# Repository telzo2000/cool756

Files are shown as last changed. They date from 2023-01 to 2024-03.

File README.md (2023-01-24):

# cool756

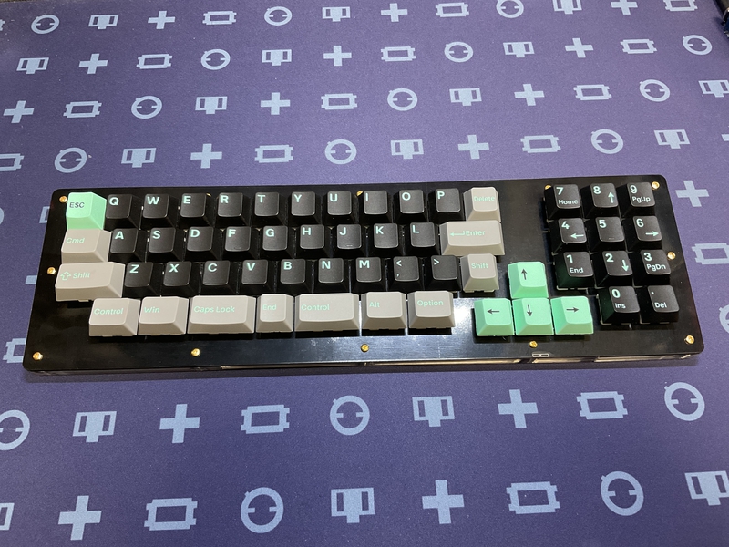
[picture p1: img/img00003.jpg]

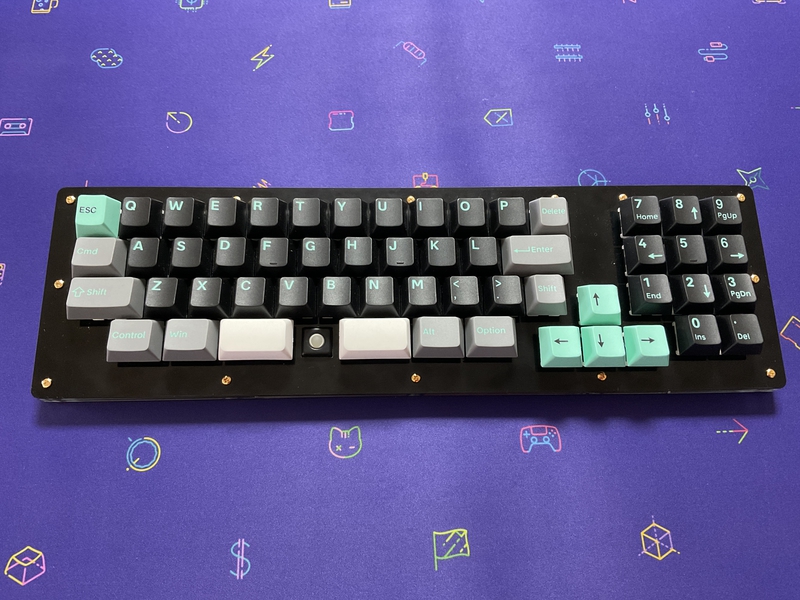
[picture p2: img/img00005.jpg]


<br>

# What is cool756?

cool756 is designed by m.ki.
<br>
cool756 is a keyboard.
<br>
This keyboard has 56 keys or 55keys and trackball.
<br>
<br>

# build guide

https://github.com/telzo2000/cool756/blob/main/buildguide_for_cool756.md
<br>

# firmware

https://github.com/telzo2000/cool756/tree/main/firmware
<br>
# Sales site

https://mki0002ozlet.booth.pm/items/4491960

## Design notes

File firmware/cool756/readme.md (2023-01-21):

# cool753rp

cool753rp

*A short description of the keyboard/project*

* Keyboard Maintainer: [m.ki](https://github.com/telzo2000)
* Hardware Supported: *The PCBs, controllers supported*
* Hardware Availability: *Links to where you can find this hardware*

Make example for this keyboard (after setting up your build environment):

    make cool753rp:default

Flashing example for this keyboard:

    make cool753rp:default:flash

See the [build environment setup](https://docs.qmk.fm/#/getting_started_build_tools) and the [make instructions](https://docs.qmk.fm/#/getting_started_make_guide) for more information. Brand new to QMK? Start with our [Complete Newbs Guide](https://docs.qmk.fm/#/newbs).

## Bootloader

Enter the bootloader in 3 ways:

* **Bootmagic reset**: Hold down the key at (0,0) in the matrix (usually the top left key or Escape) and plug in the keyboard
* **Physical reset button**: Briefly press the button on the back of the PCB - some may have pads you must short instead
* **Keycode in layout**: Press the key mapped to `QK_BOOT` if it is available

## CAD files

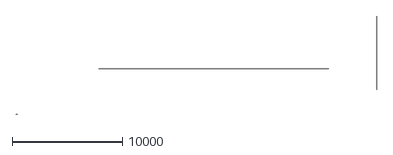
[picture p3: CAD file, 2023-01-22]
case_design/separate_moddleplate/cool756casedesign.dxf
32714.4 x 8895.2

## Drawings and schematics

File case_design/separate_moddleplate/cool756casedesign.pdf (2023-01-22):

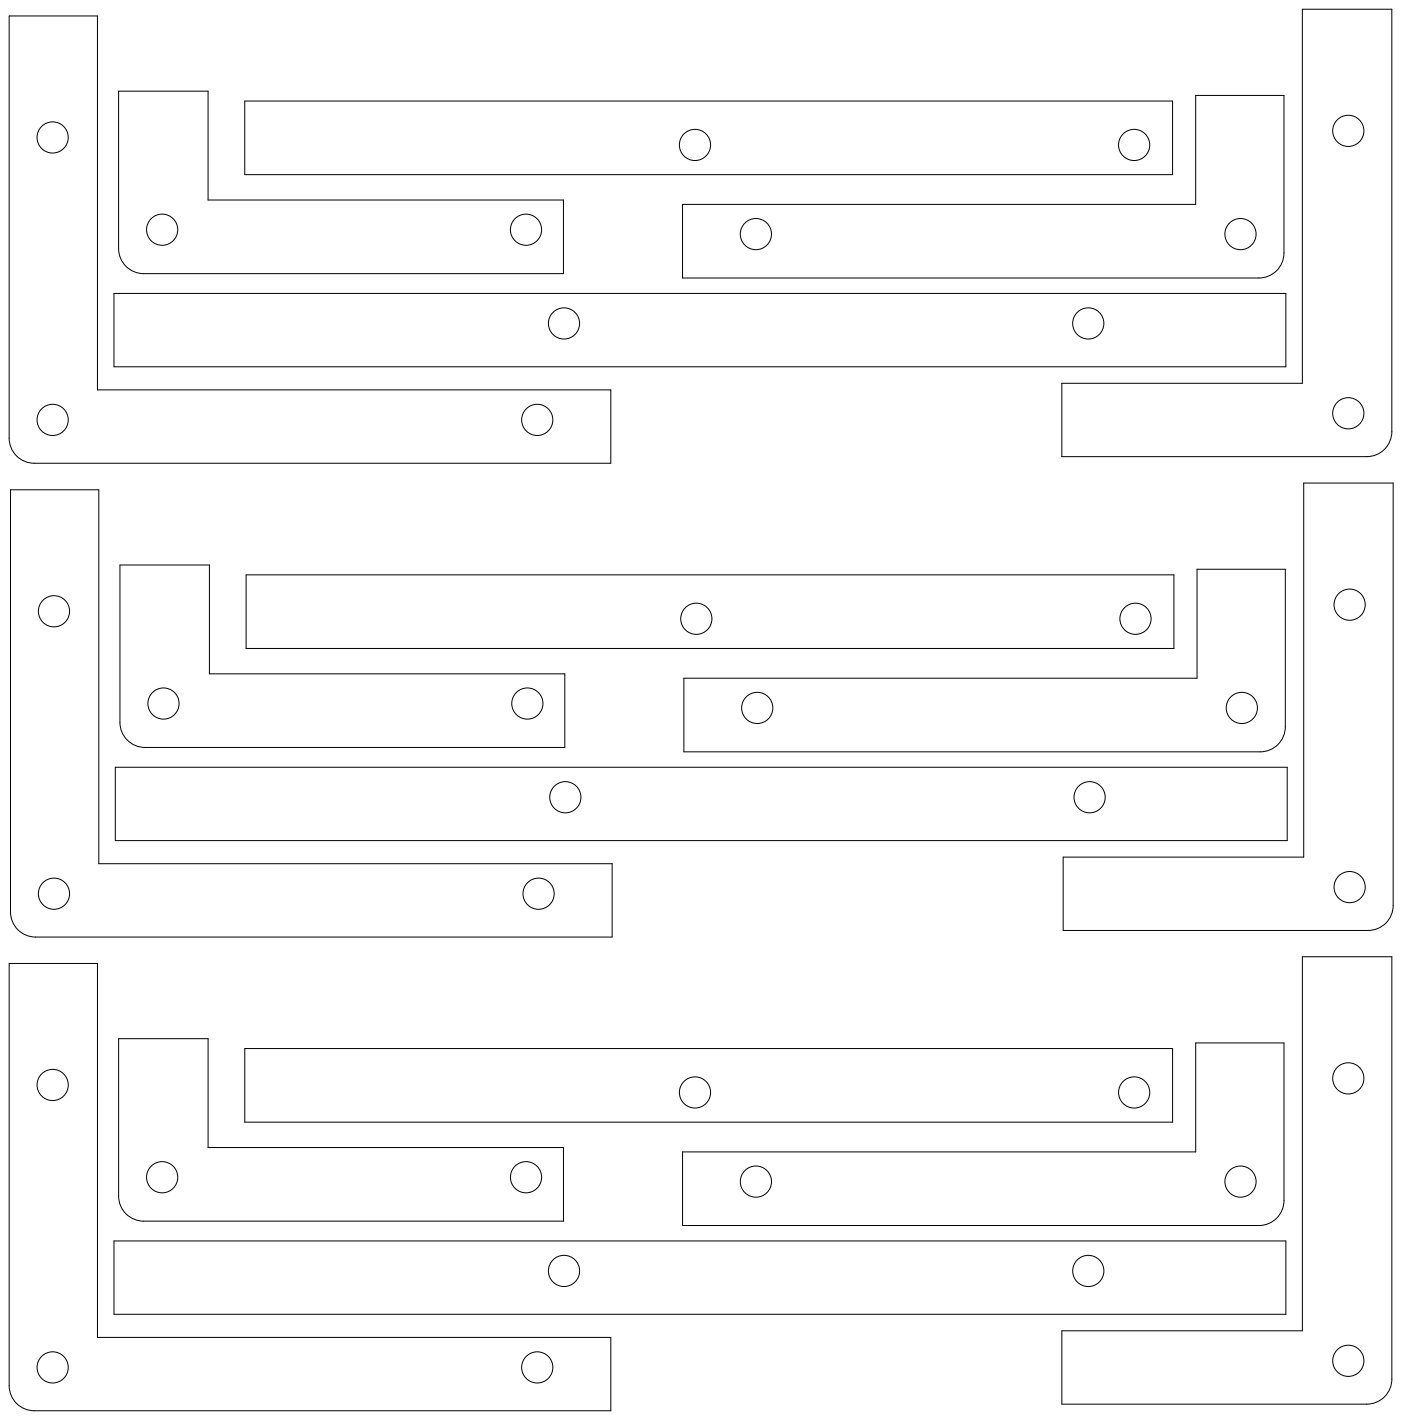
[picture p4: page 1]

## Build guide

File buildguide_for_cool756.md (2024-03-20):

# Build guide(cool756 ver.1.0)

## Parts list

| No. | Patrs | Quantity | remarks | Suppliers | Cost |
|--|--|--|--|--|--|
|番号|名前|数|備考|調達先|参考価格（送料込）|<br>
|1|PCB|1|50%keyboard<br>keyboard|[elecrow](https://www.elecrow.com)<br>[JLCPCB](https://jlcpcb.com)<br>[ALLPCB](https://www.allpcb.com)|10枚で130〜140ドル|<br>
|2-1|Switch Plate<br>スイッチプレート|１|↑|↑|↑|
|2-2|Bottom Plate<br>ボトムプレート|１|↑|↑|↑|
|3|M2screw<br>M2ネジ|26|4mm<br>CoverPlateで使用|DIYショップなど|10本で100円程度|
|4|M2spacer<br>M2スペーサー|13|8mmメス-メス|[ヒロスギネット](https://www.hirosugi-net.co.jp/shop/c/c10/)<br>[遊舎工房](https://yushakobo.jp)|20本で800円程度|
|5|pro micro|1|ピンヘッダ含む|[遊舎工房](https://yushakobo.jp)<br>[Talp Keyboard](https://talpkeyboard.net)<br>[Daily Craft Keyboard](https://shop.dailycraft.jp)等|価格変動中|
|6|Swith socket<br>スイッチソケット|56|cherry MX互換<br>無くても可|[遊舎工房](https://yushakobo.jp)<br>[Talp Keyboard](https://talpkeyboard.net)<br>[Daily Craft Keyboard](https://shop.dailycraft.jp)等|10個で165円程度|
|7|Diode<br>ダイオード|56|リードタイプでもSMDでも可|[遊舎工房](https://yushakobo.jp)<br>[Talp Keyboard](https://talpkeyboard.net)<br>[Daily Craft Keyboard](https://shop.dailycraft.jp)等|100個で220円程度から|
|８|Trackball|1|PIM447|[PIMONORI](https://shop.pimoroni.com)<br>[マルツ](https://www.marutsu.co.jp/pc/i/32844496/)|3000円程度

この他に、USBケーブル、キーキャップ等が必要です。
<br><br>

## Firmware

参考<br>

https://github.com/telzo2000/Hello_keyboard/blob/main/readme_about_firmware.md

[Here](https://github.com/telzo2000/cool756/tree/main/firmware)

<br>
[remap](https://remap-keys.app/)

<br>
<br><br>

## Build

Please read it and then work on it.
<br>
一読してから、作業をしてください。
<br><br>

### 1 Parts check

Front side（表面）<br>
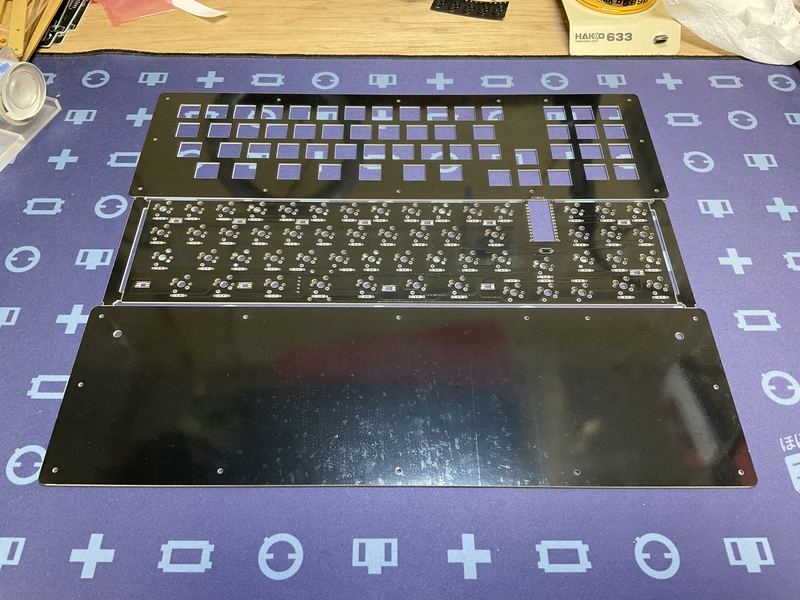
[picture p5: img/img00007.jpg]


Please cut.
<br>
切り離してください。
<br>
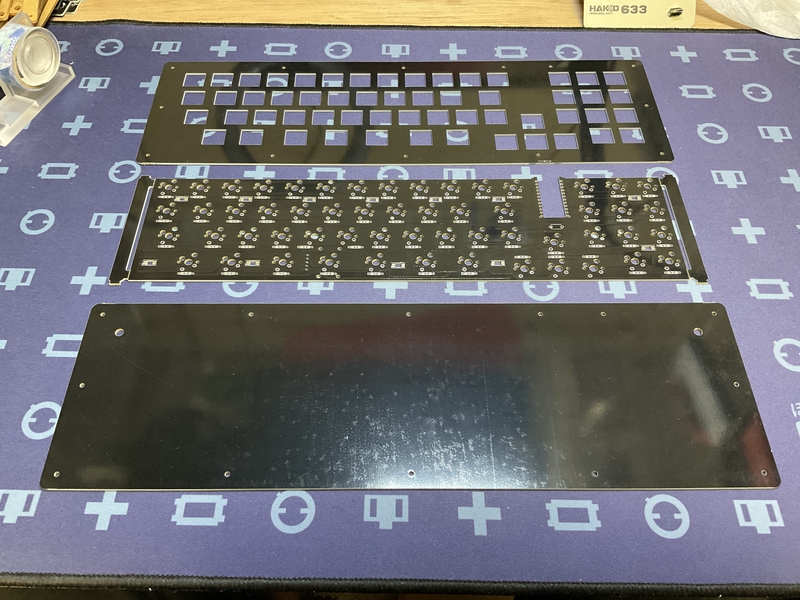
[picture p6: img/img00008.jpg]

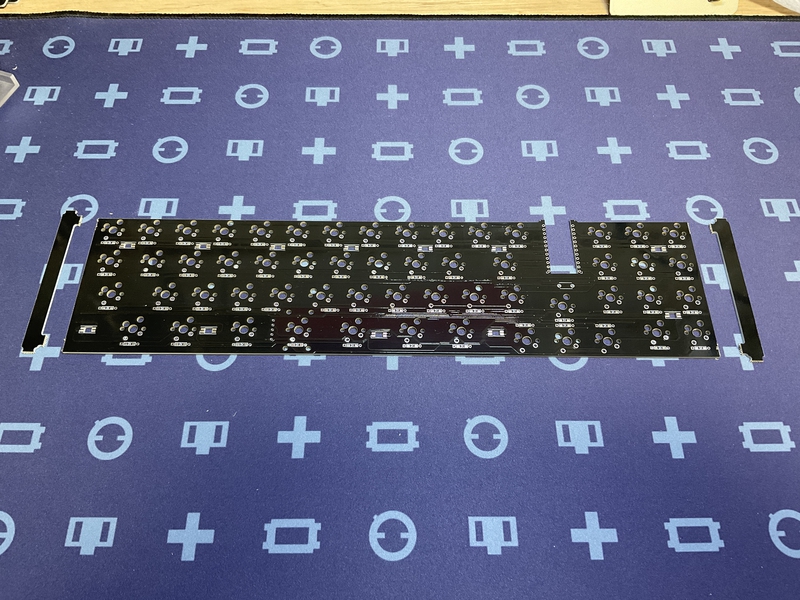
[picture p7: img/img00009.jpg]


<br><br>

### 2 Diode soldering

Solder the diode on the back side.
<br>
裏面にダイオードのハンダ付けをします。
<br>

There are lead type and SMD diodes.
<br>
ダイオードはリードタイプか、SMDがあります。
<br>
Here, we will explain the lead type soldering.
<br>
ここでは、リードタイプのハンダ付けの説明をします。
<br>
However, those who adopt the choc switch should use SMD diodes.
<br>
ただし、chocスイッチを採用する人は、SMDのダイオードを使用してください。
<br>

Use a lead bender to bend the legs of the diode.
<br>
リードベンダーを使い、ダイオードの足を曲げます。
<br>

Insert the diode into the board.
<br>
ダイオードを基板に挿しこみます。
<br>

Please pay attention to the orientation of the diode.
<br>
ダイオードの向きに注意してください。
<br>

Secure the diode with masking tape, then face up.
<br>
マスキングテープでダイオードを固定してから、表面を上にします。
<br>
Solder the protruding legs.
<br>
はみ出ている足部分に、ハンダ付けをします。
<br>
After soldering, use nippers to cut off the protruding legs.
<br>
はんだ付けが終わったら、はみ出ている足をニッパーで切り取ってください。
<br>

[８倍速　Diodeハンダ付け動画](https://youtu.be/Yaodh2-XxV4)

<br>
<br>

## Case 1
If you use cool756 with hot swap, please proceed here.
<br>
cool756をホットスワップで使用する場合、こちらを進めてください。

### 3 Soldering switch sockets

Solder the switch sockets on the back side.
<br>
裏面にスイッチソケットのハンダ付けをします。
<br>
ここでは、cherryMXスイッチのハンダ付けを行います。
<br>
Place the switch socket so that the white silk is hidden.
<br>
白いシルクが隠れるように、スイッチソケットを乗せてください。
<br>
That is the correct switch socket orientation.
<br>
それが正しいスイッチソケットの向きになります。
<br>
When using a choc switch, place the switch socket so that the letters choc are hidden.
<br>

Apply solder to both pads.
<br>
両方のパッドにハンダを盛ります。
<br>
Place the switch socket and fix it with a warm soldering iron while melting the solder.
<br>
スイッチソケットを乗せて、温めたハンダゴテで、ハンダを溶かしながら、固定します。
<br>
You can make it easier by working while holding it with tweezers.
<br>
ピンセットで押さえながら、作業をすると楽にできます。
<br>

[８倍速　Switch socketハンダ付け動画](https://youtu.be/E__mHvmIXQo)

<br><br>

### 4 Pro micro

Solder the pro micro.
<br>
pro microのハンダ付けをします。
<br>
For cool756, in order to pursue thinness, the pro micro is attached directly to the board without using a pin header.
<br>
cool756では、薄さを求めるために、pro microをピンヘッダを使わずに、基板に直付けします。
<br>
Here, it is the surface with the USB terminal and parts of the pro micro.
<br>
ここでは、pro microのUSB端子や部品が付いている表面とします。
<br>
<br>
Install the pro micro surface facing the PCB side.
A part of the PCB is cut out so that the pro micro's USB terminal and parts do not interfere with the PCB.
<br>
pro microの表面がPCB側に向くよう取り付けます。
pro microのUSB端子や部品がPCBに干渉しないよう、PCBの一部が切り抜かれています。
<br>
Place the pro micro so that the "RAW" printed on the pro micro is on the numeric keypad side.
<br>
pro microの設置向きは、pro microの「RAW」の印字がテンキー側にしてください。
<br>
<br>
＜If you have a breadboardブレッドボードがある場合＞
<br>
The installation procedure is as follows.
<br>
取り付け方は次の手順になります。
<br>
①Insert the pin header into the breadboard, and pass the pin header through the pro micro with the surface facing the breadboard.
<br>
①ブレッドボードにピンヘッダを挿して、pro microの表面をブレッドボード側に向けて、ピンヘッダを通します。
<br>
② Solder from the back side of pro micro and fix the pin header.
<br>
②pro microの裏面からハンダ付けをして、ピンヘッダを固定します。
<br>
③Pull out the pro micro from the breadboard.
<br>
③ブレッドボードからpro microを抜きます。
<br>
④Remove the plastic attached to the pin header using radio pliers or the like.
<br>
④ピンヘッダに付いているプラスチックをラジオペンチ等を用いて、外します。
<br>
⑤ Insert so that the surface of pro micro faces the PCB side. Temporarily fix with masking tape.
<br>
⑤pro microの表面がPCB側に向くように、挿します。マスキングテープ等で仮固定します。
<br>
⑥ Solder from the opposite side of the PCB where the pro micro is inserted. Cut pins that are too long with nippers.
<br>
⑥pro microを挿したPCBの反対側からハンダ付けをします。長すぎるピンはニッパー等で切ってください。
<br>
<br>
＜If you don't have a breadboardブレッドボードがない場合＞
<br>

The installation procedure is as follows.
<br>
取り付け方は次の手順になります。
<br>
①Insert the pin header from the back of pro micro, then pro micro, then PCB.
Temporarily secure with masking tape.
<br>
①ピンヘッダをpro microの裏面から、pro micro、PCBの順で挿します。
マスキングテープで仮固定します。
<br>
②Solder the pin header from the PCB side.
<br>
②PCB側からピンヘッダをハンダ付けします。
<br>
③Remove the plastic pin header on the back of the pro micro using needle nose pliers.
<br>
③pro micro裏面のピンヘッダのプラスチックをラジオペンチ等を用いて、外します。
<br>
④Solder the back of the pro micro. Cut pins that are too long with nippers.
<br>
④pro microの裏面のハンダ付けをします。長すぎるピンはニッパー等で切ってください。
<br>
<br>

### 5　Test

Please write the firmware and check the operation.
<br>
ファームウェアを書き込んで、動作確認をしてください。
<br>

Install a switch or measure continuity with tweezers, etc.
<br>
スイッチを取り付けるか、ピンセット等で導通をはかるかを行います。
<br>
<br>

Firmware

[github](https://github.com/telzo2000/cool756/tree/main/firmware)

[remap](https://remap-keys.app/)

<br>
If you have a switch that doesn't respond, use a hot soldering iron to warm up the switch socket,diode and pro micro terminals.
<br>
もし、反応しないスイッチがあったら、温めたハンダゴテで、そのスイッチソケットやダイオード、pro microの端子を温めてください。
<br>
Also make sure the diode is oriented correctly.
<br>
また、ダイオードの向きが正しいか確認してください。
<br>

### 6 Installation of key switch

Plug the key switch into the switch plate and then into the switch socket on the PCB.
<br>
スイッチプレートにキースイッチを差し込み、そのあと、PCBのスイッチソケットに差し込んでください。
<br>
<br>

### 7 Bottom plate

Insert the M2 screw from the bottom surface of the bottom plate and tighten it with the M2 spacer on the top surface.
<br>
ボトムプレートの下面からM2ネジを差し込み、上面でM2スペーサーで締めてください。
<br>
13 locations.
<br>
13箇所行います。
<br>
<br>

### Option Middle plate

If you have the optional middle plate, please install the aluminum feet first.
<br>
オプションのミドルプレートがある場合、最初に、アルミ足を取り付けてください。
<br>
<br>
Next, stack the acrylic parts so that they pass through the bottom plate spacer.
<br>
次にボトムプレートのスペーサーを通すように、アクリル部品を重ねてください。
<br>
<br>
### 8 Finish

Place the switch plate and PCB on the bottom plate and tighten the 13 M2 screws.
<br>
ボトムプレートの上に、スイッチプレートとPCBを載せて、M2ネジで13箇所を締めてください。
<br>
<br>
ミドルプレート使用時<br>


<br>
<br>

## Case2

If you want to solder directly without using a switch socket, proceed here.
<br>
スイッチソケットを使用せず、直接ハンダ付けをする場合は、こちらを進めてください。
<br>
<br>

### 3 Switch plate

Insert your favorite key switch from the top of the switch plate.
<br>
スイッチプレートの上面から、お好みのキースイッチを差し込んでください。
<br>

Note the orientation of the key switch.
<br>
キースイッチの向きに注意してください。
<br>
Good<br>
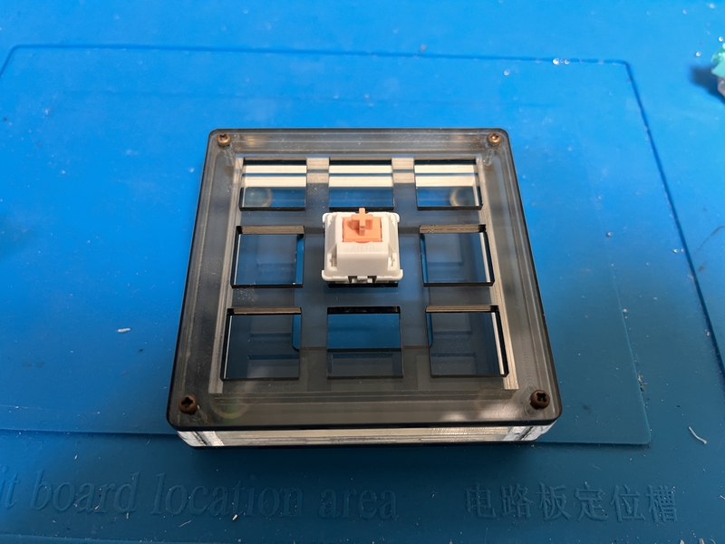
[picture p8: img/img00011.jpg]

<br>
Not good<br>
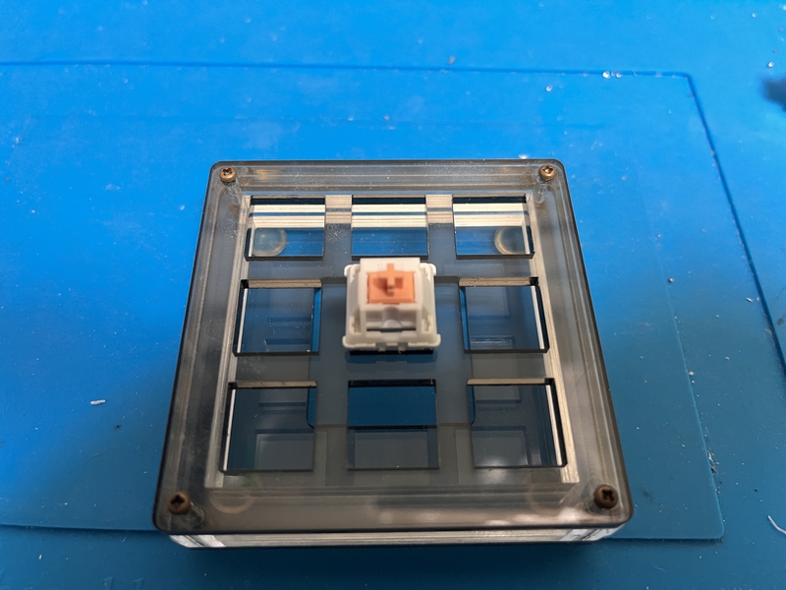
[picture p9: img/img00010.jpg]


<br>
<br>

### 4 Pro micro

Solder the pro micro.
<br>
pro microのハンダ付けをします。
<br>
For cool756, in order to pursue thinness, the pro micro is attached directly to the board without using a pin header.
<br>
cool756では、薄さを求めるために、pro microをピンヘッダを使わずに、基板に直付けします。
<br>
Here, it is the surface with the USB terminal and parts of the pro micro.
<br>
ここでは、pro microのUSB端子や部品が付いている表面とします。
<br>
<br>
Install the pro micro surface facing the PCB side.
A part of the PCB is cut out so that the pro micro's USB terminal and parts do not interfere with the PCB.
<br>
pro microの表面がPCB側に向くよう取り付けます。
pro microのUSB端子や部品がPCBに干渉しないよう、PCBの一部が切り抜かれています。
<br>
Place the pro micro so that the "RAW" printed on the pro micro is on the numeric keypad side.
<br>
pro microの設置向きは、pro microの「RAW」の印字がテンキー側にしてください。
<br>
<br>
＜If you have a breadboardブレッドボードがある場合＞
<br>
The installation procedure is as follows.
<br>
取り付け方は次の手順になります。
<br>
①Insert the pin header into the breadboard, and pass the pin header through the pro micro with the surface facing the breadboard.
<br>
①ブレッドボードにピンヘッダを挿して、pro microの表面をブレッドボード側に向けて、ピンヘッダを通します。
<br>
② Solder from the back side of pro micro and fix the pin header.
<br>
②pro microの裏面からハンダ付けをして、ピンヘッダを固定します。
<br>
③Pull out the pro micro from the breadboard.
<br>
③ブレッドボードからpro microを抜きます。
<br>
④Remove the plastic attached to the pin header using radio pliers or the like.
<br>
④ピンヘッダに付いているプラスチックをラジオペンチ等を用いて、外します。
<br>
⑤ Insert so that the surface of pro micro faces the PCB side. Temporarily fix with masking tape.
<br>
⑤pro microの表面がPCB側に向くように、挿します。マスキングテープ等で仮固定します。
<br>
⑥ Solder from the opposite side of the PCB where the pro micro is inserted. Cut pins that are too long with nippers.
<br>
⑥pro microを挿したPCBの反対側からハンダ付けをします。長すぎるピンはニッパー等で切ってください。
<br>
<br>
＜If you don't have a breadboardブレッドボードがない場合＞
<br>

The installation procedure is as follows.
<br>
取り付け方は次の手順になります。
<br>
①Insert the pin header from the back of pro micro, then pro micro, then PCB.
Temporarily secure with masking tape.
<br>
①ピンヘッダをpro microの裏面から、pro micro、PCBの順で挿します。
マスキングテープで仮固定します。
<br>
②Solder the pin header from the PCB side.
<br>
②PCB側からピンヘッダをハンダ付けします。
<br>
③Remove the plastic pin header on the back of the pro micro using needle nose pliers.
<br>
③pro micro裏面のピンヘッダのプラスチックをラジオペンチ等を用いて、外します。
<br>
④Solder the back of the pro micro. Cut pins that are too long with nippers.
<br>
④pro microの裏面のハンダ付けをします。長すぎるピンはニッパー等で切ってください。
<br>
<br>

### 5　Test

Please write the firmware and check the operation.
<br>
ファームウェアを書き込んで、動作確認をしてください。
<br>
Check for continuity with tweezers or the like.
<br>
ピンセット等で導通をはかるかを行います。
<br>
<br>

Firmware

[github](https://github.com/telzo2000/cool756/tree/main/firmware)

[remap](https://remap-keys.app/)

<br>
If you have a switch that doesn't respond, use a hot soldering iron to warm up the diode and pro micro terminals.
<br>
もし、反応しないスイッチがあったら、温めたハンダゴテで、ダイオードやpro microの端子を温めてください。
<br>
Also make sure the diode is oriented correctly.
<br>
また、ダイオードの向きが正しいか確認してください。
<br>
<br>

### 6 Soldering keyswitch

Turn the switch plate with the key switch upside down.
<br>
キースイッチの刺さったスイッチプレートを逆さの向きにします。
<br>
Stack the PCBs in the same way upside down.
<br>
同じ様に逆さの向きにしたPCBを重ねます。
<br>
<br>
Check to see if the key switch legs are sticking out of the PCB.
<br>
PCBからキースイッチの足が出ているか確認してください。
<br>
If it's OK, solder all the key switch legs and PCB terminals.
<br>
問題ないのであれば、全てのキースイッチの足とPCBの端子をはんだ付けします。
<br>
<br>
### 7 Bottom plate

Insert the M2 screw from the bottom surface of the bottom plate and tighten it with the M2 spacer on the top surface.
<br>
ボトムプレートの下面からM2ネジを差し込み、上面でM2スペーサーで締めてください。
<br>
13 locations.
<br>
13箇所行います。
<br>
<br>

### Option Middle plate

If you have the optional middle plate, please install the aluminum feet first.
<br>
オプションのミドルプレートがある場合、最初に、アルミ足を取り付けてください。
<br>
<br>
Next, stack the acrylic parts so that they pass through the bottom plate spacer.
<br>
次にボトムプレートのスペーサーを通すように、アクリル部品を重ねてください。
<br>
<br>

### 8 Finish

Place the switch plate and PCB on the bottom plate and tighten the 13 M2 screws.
<br>
ボトムプレートの上に、スイッチプレートとPCBを載せて、M2ネジで13箇所を締めてください。
<br>
<br>
ミドルプレート使用時<br>



<br>
<br>

### Option  Installing PIM447 Trackball

A PIM447trackball can be attached to the cool756.
<br><br>
cool756に、PIM447trackballを取り付けることができます。
<br>
<br>
In addition to PIM447, four M2 screws 8mm (low head screws), eight M2 nuts, and a pin header are required.
<br><br>
PIM447との他に、M2ネジ8mm４本（低頭ネジ）、M2ナット８個、ピンヘッダが必要となります。
<br><br>
上からネジを差し込み、下でナットを締めます。<br>
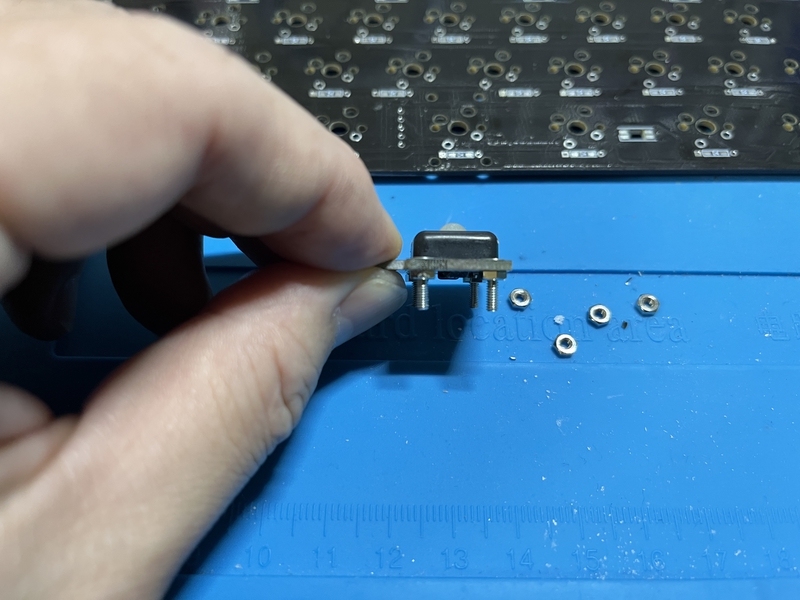
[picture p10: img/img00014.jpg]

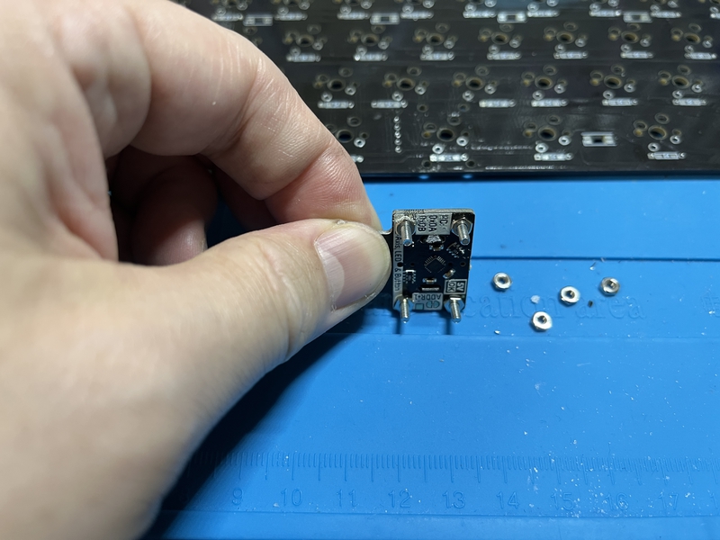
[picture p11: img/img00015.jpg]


PCBに差し込んで、その下からナットを締めます。<br>
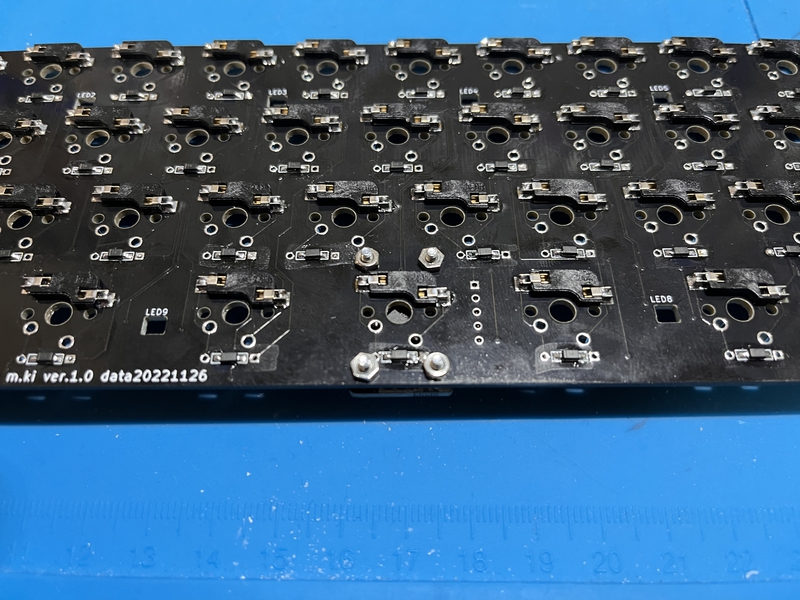
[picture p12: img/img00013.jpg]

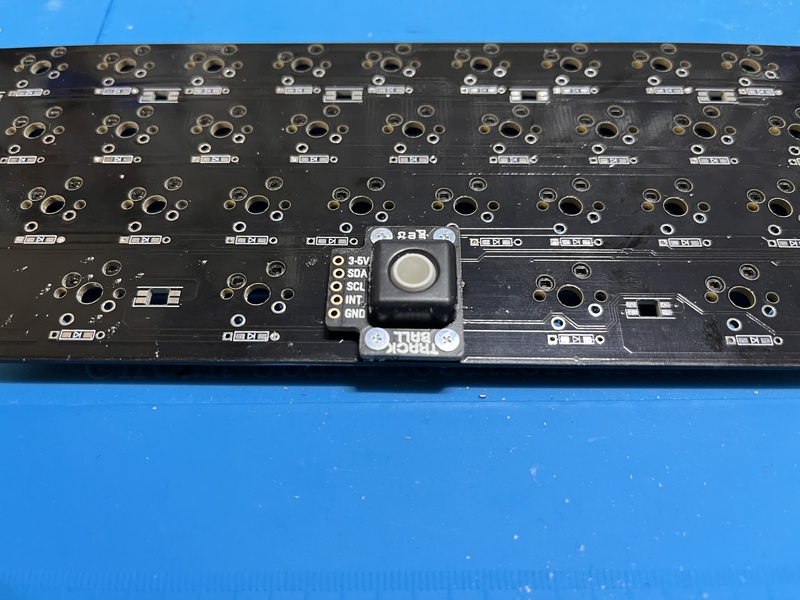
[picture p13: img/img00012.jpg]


ピンの長さを調節して、差し込んではんだ付けをします。<br>
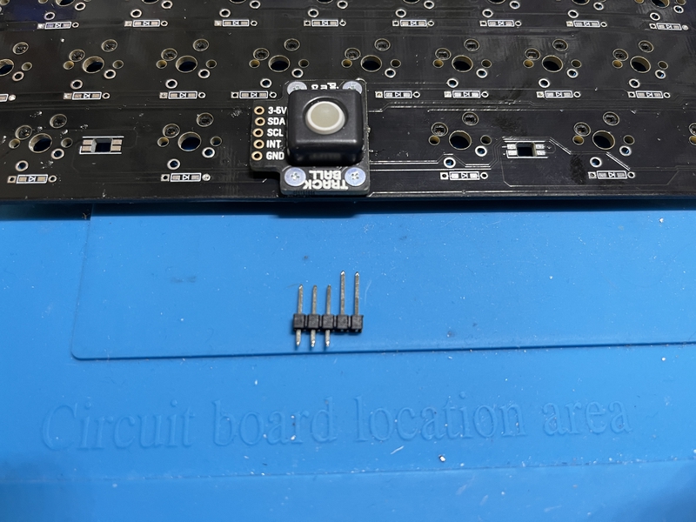
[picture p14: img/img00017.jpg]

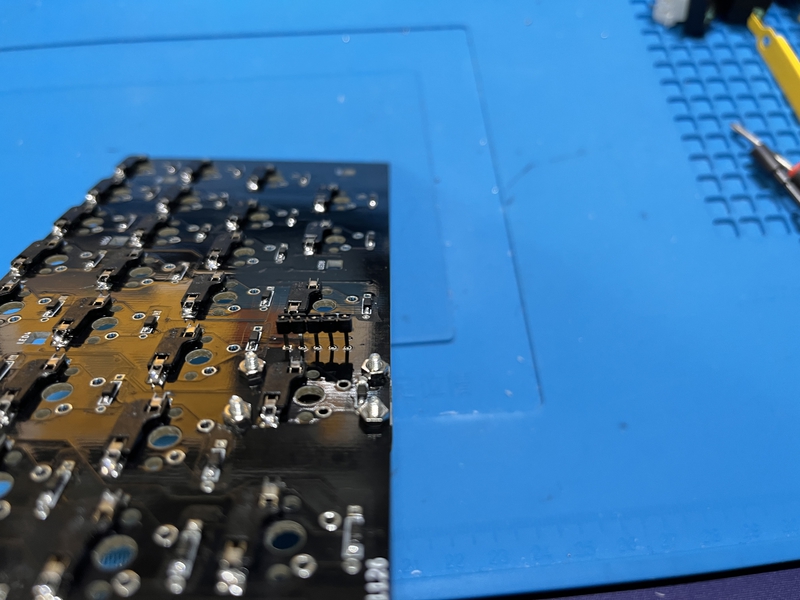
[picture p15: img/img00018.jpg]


スイッチプレートを被せると、このようになります。<br>
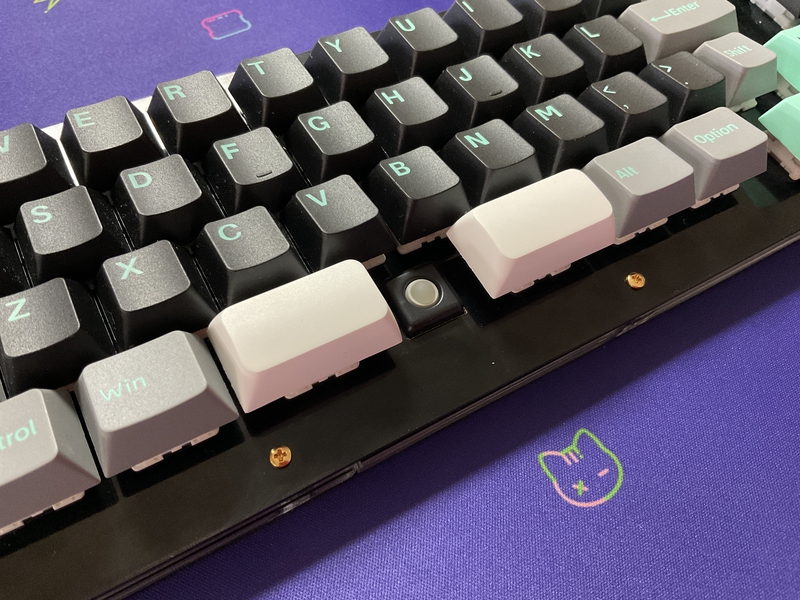
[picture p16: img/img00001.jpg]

<br>
<br>

Have a fun selfmade keyboard life!
<br>
楽しい自作キーボード生活を!<br>



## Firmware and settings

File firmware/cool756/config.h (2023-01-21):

/*
Copyright 2021 m.ki

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
You should have received a copy of the GNU General Public License
along with this program.  If not, see <http://www.gnu.org/licenses/>.
*/

#pragma once

#include "config_common.h"

/* USB Device descriptor parameter */
#define VENDOR_ID    0x4D43
#define PRODUCT_ID   0x0756
#define DEVICE_VER   0x0001
#define MANUFACTURER m.ki
#define PRODUCT      cool756

/* key matrix size */
#define MATRIX_ROWS 8
#define MATRIX_COLS 7

/*
 * Keyboard Matrix Assignments
 *
 * Change this to how you wired your keyboard
 * COLS: AVR pins used for columns, left to right
 * ROWS: AVR pins used for rows, top to bottom
 * DIODE_DIRECTION: COL2ROW = COL = Anode (+), ROW = Cathode (-, marked on diode)
 *                  ROW2COL = ROW = Anode (+), COL = Cathode (-, marked on diode)
 *
 */
#define MATRIX_ROW_PINS { F4, F5, F6, F7, B1, B3, B6, B5 }
#define MATRIX_COL_PINS { D3, D2, C6, D7, E6, B4, B2 }
//#define UNUSED_PINS

#define DIODE_DIRECTION ROW2COL


#define RGB_DI_PIN D4
#ifdef RGB_DI_PIN
#    define RGBLED_NUM 16
#    define RGBLIGHT_HUE_STEP 16
#    define RGBLIGHT_SAT_STEP 16
#    define RGBLIGHT_VAL_STEP 16
#    define RGBLIGHT_LIMIT_VAL 255 /* The maximum brightness level */
#    define RGBLIGHT_SLEEP  /* If defined, the RGB lighting will be switched off when the host goes to sleep */
/*== all animations enable ==*/
#    define RGBLIGHT_ANIMATIONS
/*== or choose animations ==*/
#    define RGBLIGHT_EFFECT_BREATHING
#    define RGBLIGHT_EFFECT_RAINBOW_MOOD
#    define RGBLIGHT_EFFECT_RAINBOW_SWIRL
#    define RGBLIGHT_EFFECT_SNAKE
#    define RGBLIGHT_EFFECT_KNIGHT
#    define RGBLIGHT_EFFECT_CHRISTMAS
#    define RGBLIGHT_EFFECT_STATIC_GRADIENT
#    define RGBLIGHT_EFFECT_RGB_TEST
#    define RGBLIGHT_EFFECT_ALTERNATING
/*== customize breathing effect ==*/
/*==== (DEFAULT) use fixed table instead of exp() and sin() ====*/
#    define RGBLIGHT_BREATHE_TABLE_SIZE 256      // 256(default) or 128 or 64
/*==== use exp() and sin() ====*/
#    define RGBLIGHT_EFFECT_BREATHE_CENTER 1.85  // 1 to 2.7
#    define RGBLIGHT_EFFECT_BREATHE_MAX    255   // 0 to 255
#endif

/* Debounce reduces chatter (unintended double-presses) - set 0 if debouncing is not needed */
#define DEBOUNCE 5

/* define if matrix has ghost (lacks anti-ghosting diodes) */
//#define MATRIX_HAS_GHOST

/* Mechanical locking support. Use KC_LCAP, KC_LNUM or KC_LSCR instead in keymap */
//#define LOCKING_SUPPORT_ENABLE
/* Locking resynchronize hack */
//#define LOCKING_RESYNC_ENABLE

/* If defined, GRAVE_ESC will always act as ESC when CTRL is held.
 * This is useful for the Windows task manager shortcut (ctrl+shift+esc).
 */
//#define GRAVE_ESC_CTRL_OVERRIDE

/*
 * Force NKRO
 *
 * Force NKRO (nKey Rollover) to be enabled by default, regardless of the saved
 * state in the bootmagic EEPROM settings. (Note that NKRO must be enabled in the
 * makefile for this to work.)
 *
 * If forced on, NKRO can be disabled via magic key (default = LShift+RShift+N)
 * until the next keyboard reset.
 *
 * NKRO may prevent your keystrokes from being detected in the BIOS, but it is
 * fully operational during normal computer usage.
 *
 * For a less heavy-handed approach, enable NKRO via magic key (LShift+RShift+N)
 * or via bootmagic (hold SPACE+N while plugging in the keyboard). Once set by
 * bootmagic, NKRO mode will always be enabled until it is toggled again during a
 * power-up.
 *
 */
//#define FORCE_NKRO

/*
 * Feature disable options
 *  These options are also useful to firmware size reduction.
 */

/* disable debug print */
//#define NO_DEBUG

/* disable print */
//#define NO_PRINT

/* disable action features */
//#define NO_ACTION_LAYER
//#define NO_ACTION_TAPPING
//#define NO_ACTION_ONESHOT

/* disable these deprecated features by default */
//#define NO_ACTION_MACRO
//#define NO_ACTION_FUNCTION

/* Bootmagic Lite key configuration */
//#define BOOTMAGIC_LITE_ROW 0
//#define BOOTMAGIC_LITE_COLUMN 0

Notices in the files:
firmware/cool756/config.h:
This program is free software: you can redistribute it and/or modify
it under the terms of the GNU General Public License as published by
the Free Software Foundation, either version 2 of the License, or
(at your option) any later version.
